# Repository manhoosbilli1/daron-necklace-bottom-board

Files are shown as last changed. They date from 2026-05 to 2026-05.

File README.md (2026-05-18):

# Daron_necklace_bottom

Bottom half of wearable LED necklace - power, haptic, USB-C charging

## At a Glance

- **Status**: Routed
- **Board size**: 20 x 20 mm
- **Layers**: 2
- **Components**: 42
- **Key ICs**:
  - U1: MCP73831-2-MC
  - U2: FH35C-11S-0.3SHW(50)_C7427016
  - U3: TPS63070RNMR
  - U7: DRV2605LDGS

## Schematic

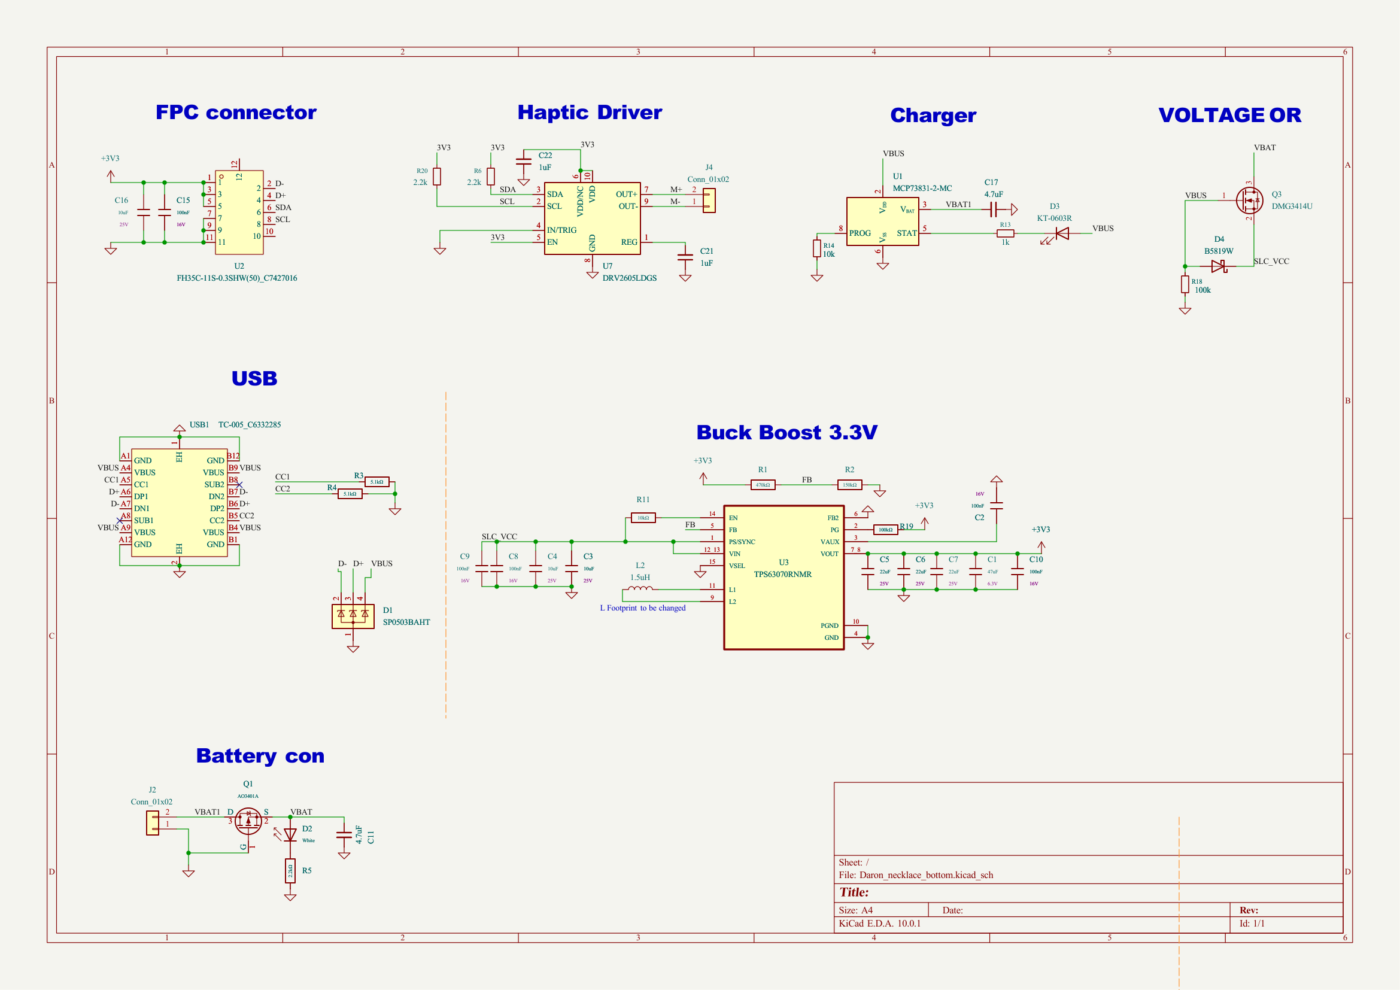
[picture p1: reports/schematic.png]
Schematic


Full PDF: [reports/schematic.pdf](reports/schematic.pdf)

## Component Roles

- **TPS63070RNMR** (U3) - buck-boost regulator (3.3 V output); handles wide LiPo voltage swing
- **DRV2605LDGS** (U7) - haptic motor driver for tactile feedback
- **MCP73831-2-MC** (U1) - single-cell LiPo charger
- **AO3401A** (Q1) - P-channel MOSFET for power switching / load enable
- **DMG3414U** (Q3) - N-channel MOSFET (companion to Q1 for full PowerPath)
- **FH35C-11S-0.3SHW** (U2) - 0.3 mm-pitch FPC connector for the top-board flex link
- **TC-005** (USB1) - micro USB-C receptacle (compact variant)
- **SP0503BAHT** (D1) - 3-line ESD protection on USB data lines
- **KT-0603R** (D3) - status LED

> Companion to the top-board (LED-driving half). The top board handles the addressable LED chain; this board handles power, charging, haptics.

## PCB

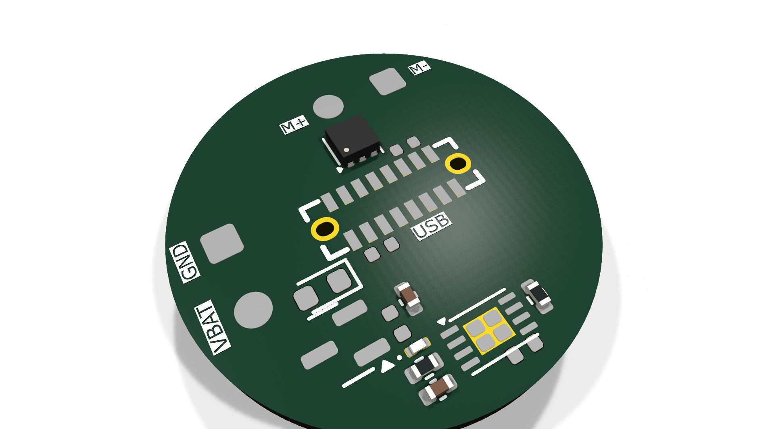
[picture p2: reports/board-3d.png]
3D top


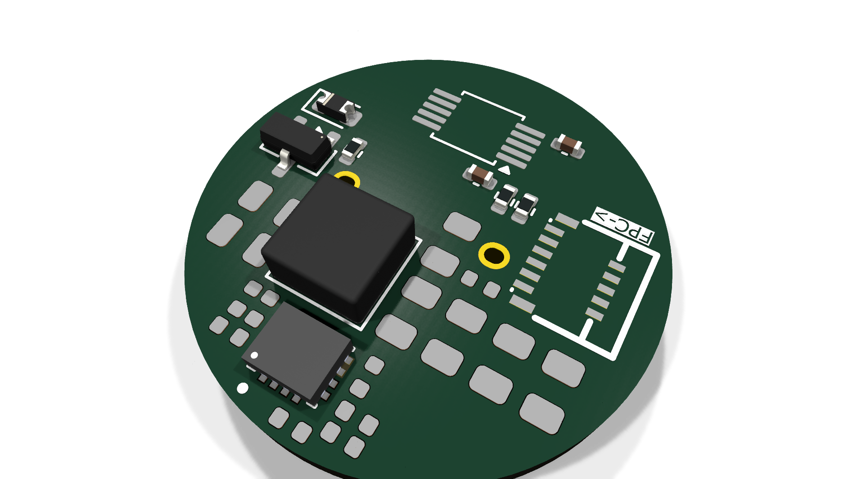
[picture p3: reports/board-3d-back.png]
3D bottom


**Top copper**

PCB top

**Bottom copper**

PCB bottom

## Bill of Materials

| Refs | Value | Footprint | Qty | MPN | LCSC |
|---|---|---|----:|-----|---|
| C1 | 47uF | PCM_JLCPCB:C_0805 | 1 |  | [C16780](https://www.lcsc.com/product-detail/_C16780.html) |
| C2,C8-C10,C15 | 100nF | PCM_JLCPCB:C_0402 | 5 |  | [C1525](https://www.lcsc.com/product-detail/_C1525.html) |
| C3,C4,C16 | 10uF | PCM_JLCPCB:C_0805 | 3 |  | [C15850](https://www.lcsc.com/product-detail/_C15850.html) |
| C5-C7 | 22uF | PCM_JLCPCB:C_0805 | 3 |  | [C45783](https://www.lcsc.com/product-detail/_C45783.html) |
| C11,C17 | 4.7uF | Capacitor_SMD:C_0402_1005Metric | 2 |  |  |
| C21,C22 | 1uF | Capacitor_SMD:C_0402_1005Metric | 2 |  |  |
| D1 | SP0503BAHT | Package_SON:WSON-6-1EP_2x2mm_P0.65mm_EP1x1.6mm | 1 |  |  |
| D2 | White | PCM_JLCPCB:D_0603 | 1 |  | [C2290](https://www.lcsc.com/product-detail/_C2290.html) |
| D3 | KT-0603R | LED_SMD:LED_0201_0603Metric | 1 |  |  |
| D4 | B5819W | Diode_SMD:D_0603_1608Metric | 1 |  |  |
| J2,J4 | Conn_01x02 | Connector_Wire:SolderWire-0.1sqmm_1x02_P3.6mm_D0.4mm_OD1mm | 2 |  |  |
| L2 | 1.5uH | Inductor_SMD:L_Coilcraft_XAL4020-XXX | 1 |  |  |
| Q1 | AO3401A | PCM_JLCPCB:Q_SOT-23 | 1 |  | [C15127](https://www.lcsc.com/product-detail/_C15127.html) |
| Q3 | DMG3414U | Package_TO_SOT_SMD:SOT-23 | 1 |  |  |
| R1 | 470kΩ | PCM_JLCPCB:R_0402 | 1 |  | [C25790](https://www.lcsc.com/product-detail/_C25790.html) |
| R2 | 150kΩ | PCM_JLCPCB:R_0402 | 1 |  | [C25755](https://www.lcsc.com/product-detail/_C25755.html) |
| R3,R4 | 5.1kΩ | PCM_JLCPCB:R_0402 | 2 |  | [C25905](https://www.lcsc.com/product-detail/_C25905.html) |
| R5 | 2.2kΩ | PCM_JLCPCB:R_0402 | 1 |  | [C25879](https://www.lcsc.com/product-detail/_C25879.html) |
| R6,R20 | 2.2k | Resistor_SMD:R_0402_1005Metric | 2 |  |  |
| R11 | 10kΩ | PCM_JLCPCB:R_0402 | 1 |  | [C25744](https://www.lcsc.com/product-detail/_C25744.html) |
| R13 | 1k | Resistor_SMD:R_0402_1005Metric | 1 |  |  |
| R14 | 10k | Resistor_SMD:R_0402_1005Metric | 1 |  |  |
| R18 | 100k | Resistor_SMD:R_0402_1005Metric | 1 |  |  |
| R19 | 100kΩ | PCM_JLCPCB:R_0402 | 1 |  | [C25741](https://www.lcsc.com/product-detail/_C25741.html) |
| U1 | MCP73831-2-MC | Package_DFN_QFN:DFN-8-1EP_3x2mm_P0.5mm_EP1.7x1.4mm | 1 |  |  |
| U2 | FH35C-11S-0.3SHW(50)_C7427016 | FH35C_11S_0_3SHW_50_:FPC-SMD_FH35C-11S-0.3SHW | 1 |  |  |
| U3 | TPS63070RNMR | TPS63070RNMR:VREG_TPS63070RNMR | 1 |  |  |
| U7 | DRV2605LDGS | Package_SO:VSSOP-10_3x3mm_P0.5mm | 1 |  |  |
| USB1 | TC-005_C6332285 | usbc:USB-C-SMD_TC-005 | 1 |  |  |

_17 of 29 line items don't have an LCSC code in the schematic - search [LCSC](https://www.lcsc.com/) or [JLC parts search](https://jlcsearch.tscircuit.com/) by MPN or footprint when sourcing._

## Files

- `Daron_necklace_bottom.kicad_pro` - KiCad project
- `Daron_necklace_bottom.kicad_sch` - schematic source
- `Daron_necklace_bottom.kicad_pcb` - PCB layout source
- `reports/schematic.pdf` - full schematic (printable)
- `reports/bom.csv` - bill of materials
- `reports/pcb-top.svg`, `reports/pcb-bottom.svg` - copper artwork
- `reports/board-stats.json` - KiCad-generated board statistics

---

_Renders and metadata auto-generated by `Backup-KiCadProject.ps1` using KiCad 10.0._

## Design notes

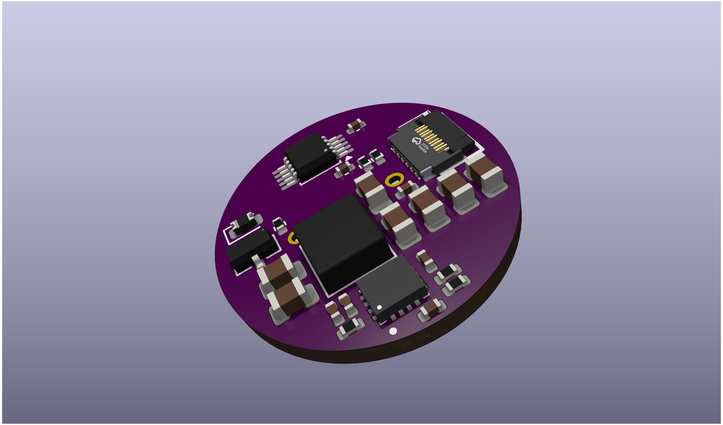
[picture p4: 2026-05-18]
pics/back_v1.png

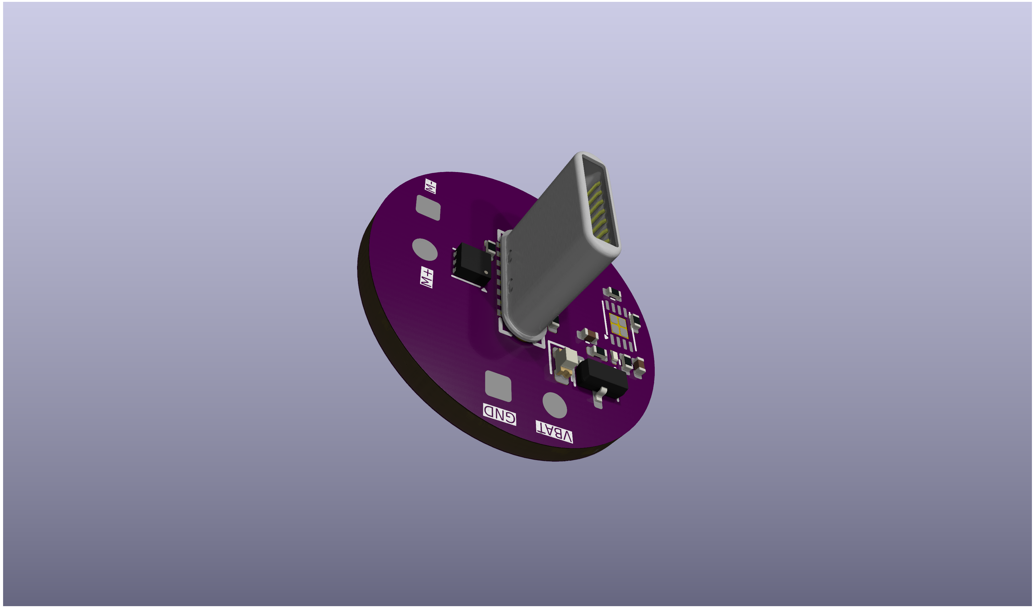
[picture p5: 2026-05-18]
pics/front_v1.png

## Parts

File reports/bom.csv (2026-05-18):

Refs | Value | Footprint | Qty | Description | Mfr | MPN | LCSC
C1 | 47uF | PCM_JLCPCB:C_0805 | 1 | 6.3V 47uF X5R ±20% 0805 Multilayer Ceramic Capacitors MLCC - SMD/SMT ROHS | Samsung Electro-Mechanics |  | C16780
C2,C8-C10,C15 | 100nF | PCM_JLCPCB:C_0402 | 5 | 16V 100nF X7R ±10% 0402 Multilayer Ceramic Capacitors MLCC - SMD/SMT ROHS | Samsung Electro-Mechanics |  | C1525
C3,C4,C16 | 10uF | PCM_JLCPCB:C_0805 | 3 | 25V 10uF X5R ±10% 0805 Multilayer Ceramic Capacitors MLCC - SMD/SMT ROHS | Samsung Electro-Mechanics |  | C15850
C5-C7 | 22uF | PCM_JLCPCB:C_0805 | 3 | 25V 22uF X5R ±20% 0805 Multilayer Ceramic Capacitors MLCC - SMD/SMT ROHS | Samsung Electro-Mechanics |  | C45783
C11,C17 | 4.7uF | Capacitor_SMD:C_0402_1005Metric | 2 | Unpolarized capacitor, small symbol
C21,C22 | 1uF | Capacitor_SMD:C_0402_1005Metric | 2 | Unpolarized capacitor, small symbol
D1 | SP0503BAHT | Package_SON:WSON-6-1EP_2x2mm_P0.65mm_EP1x1.6mm | 1 | TVS Diode Array, 5.5V Standoff, 3 Channels, SOT-143 package
D2 | White | PCM_JLCPCB:D_0603 | 1 | White 0603 LED Indication - Discrete ROHS | Hubei KENTO Elec |  | C2290
D3 | KT-0603R | LED_SMD:LED_0201_0603Metric | 1 | Light emitting diode
D4 | B5819W | Diode_SMD:D_0603_1608Metric | 1 | Schottky diode
J2,J4 | Conn_01x02 | Connector_Wire:SolderWire-0.1sqmm_1x02_P3.6mm_D0.4mm_OD1mm | 2 | Generic connector, single row, 01x02, script generated (kicad-library-utils/schlib/autogen/connector/)
L2 | 1.5uH | Inductor_SMD:L_Coilcraft_XAL4020-XXX | 1 | Inductor
Q1 | AO3401A | PCM_JLCPCB:Q_SOT-23 | 1 | 30V 4A 44mΩ@10V,4.3A 1.4W 1.3V@250uA 1 Piece P-Channel SOT-23 MOSFETs ROHS | Alpha & Omega Semicon |  | C15127
Q3 | DMG3414U | Package_TO_SOT_SMD:SOT-23 | 1 | 4.2A Id, 20V Vds, N-Channel MOSFET, SOT-23
R1 | 470kΩ | PCM_JLCPCB:R_0402 | 1 | 62.5mW Thick Film Resistors 50V ±100ppm/°C ±1% 470kΩ 0402 Chip Resistor - Surface Mount ROHS | UNI-ROYAL(Uniroyal Elec) |  | C25790
R2 | 150kΩ | PCM_JLCPCB:R_0402 | 1 | 62.5mW Thick Film Resistors 50V ±100ppm/°C ±1% 150kΩ 0402 Chip Resistor - Surface Mount ROHS | UNI-ROYAL(Uniroyal Elec) |  | C25755
R3,R4 | 5.1kΩ | PCM_JLCPCB:R_0402 | 2 | 62.5mW Thick Film Resistors 50V ±100ppm/°C ±1% 5.1kΩ 0402 Chip Resistor - Surface Mount ROHS | UNI-ROYAL(Uniroyal Elec) |  | C25905
R5 | 2.2kΩ | PCM_JLCPCB:R_0402 | 1 | 62.5mW Thick Film Resistors 50V ±100ppm/°C ±1% 2.2kΩ 0402 Chip Resistor - Surface Mount ROHS | UNI-ROYAL(Uniroyal Elec) |  | C25879
R6,R20 | 2.2k | Resistor_SMD:R_0402_1005Metric | 2 | Resistor, small symbol
R11 | 10kΩ | PCM_JLCPCB:R_0402 | 1 | 62.5mW Thick Film Resistors 50V ±100ppm/°C ±1% 10kΩ 0402 Chip Resistor - Surface Mount ROHS | UNI-ROYAL(Uniroyal Elec) |  | C25744
R13 | 1k | Resistor_SMD:R_0402_1005Metric | 1 | Resistor, small symbol
R14 | 10k | Resistor_SMD:R_0402_1005Metric | 1 | Resistor, small symbol
R18 | 100k | Resistor_SMD:R_0402_1005Metric | 1 | Resistor, small symbol
R19 | 100kΩ | PCM_JLCPCB:R_0402 | 1 | 62.5mW Thick Film Resistors 50V ±100ppm/°C ±1% 100kΩ 0402 Chip Resistor - Surface Mount ROHS | UNI-ROYAL(Uniroyal Elec) |  | C25741
U1 | MCP73831-2-MC | Package_DFN_QFN:DFN-8-1EP_3x2mm_P0.5mm_EP1.7x1.4mm | 1 | Single cell, Li-Ion/Li-Po charge management controller, 4.20V, Tri-State Status Output, in DFN-8 package
U2 | FH35C-11S-0.3SHW(50)_C7427016 | FH35C_11S_0_3SHW_50_:FPC-SMD_FH35C-11S-0.3SHW | 1
U3 | TPS63070RNMR | TPS63070RNMR:VREG_TPS63070RNMR | 1
U7 | DRV2605LDGS | Package_SO:VSSOP-10_3x3mm_P0.5mm | 1 | Haptic driver for LRAs and ERMs with effect library, 2-5.2V, VSSOP-10
USB1 | TC-005_C6332285 | usbc:USB-C-SMD_TC-005 | 1

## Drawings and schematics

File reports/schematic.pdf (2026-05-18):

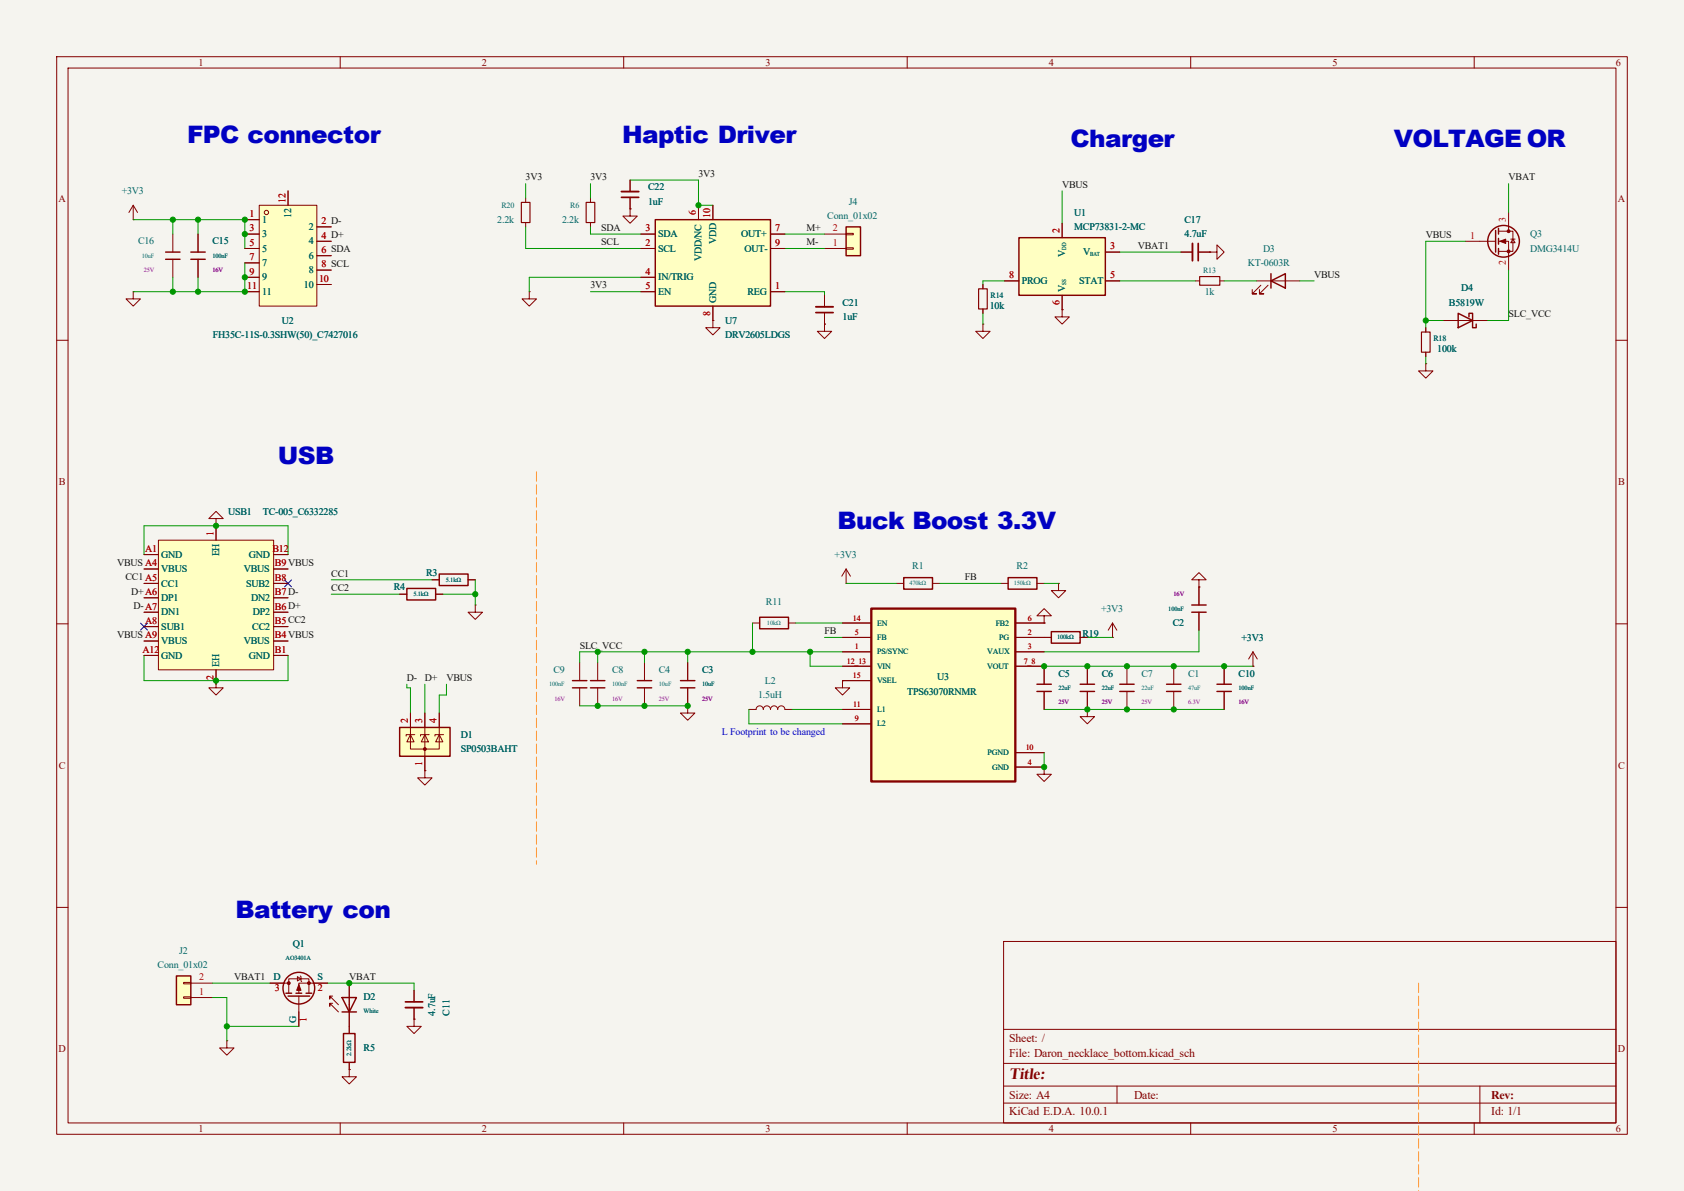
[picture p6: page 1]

2 GND A1 VBUS A4 CC1 A5 DP1 A6 DN1 A7 SUB1 A8 VBUS A9 GND A12 GND B1 VBUS B4 CC2 B5 DP2 B6 DN2 B7 SUB2 B8 VBUS B9 GND B12 USB1 TC-005_C6332285 R3

2 GND A1 VBUS A4 CC1 A5 DP1 A6 DN1 A7 SUB1 A8 VBUS A9 GND A12 GND B1 VBUS B4 CC2 B5 DP2 B6 DN2 B7 SUB2 B8 VBUS B9 GND B12 R3

L Footprint to be changed

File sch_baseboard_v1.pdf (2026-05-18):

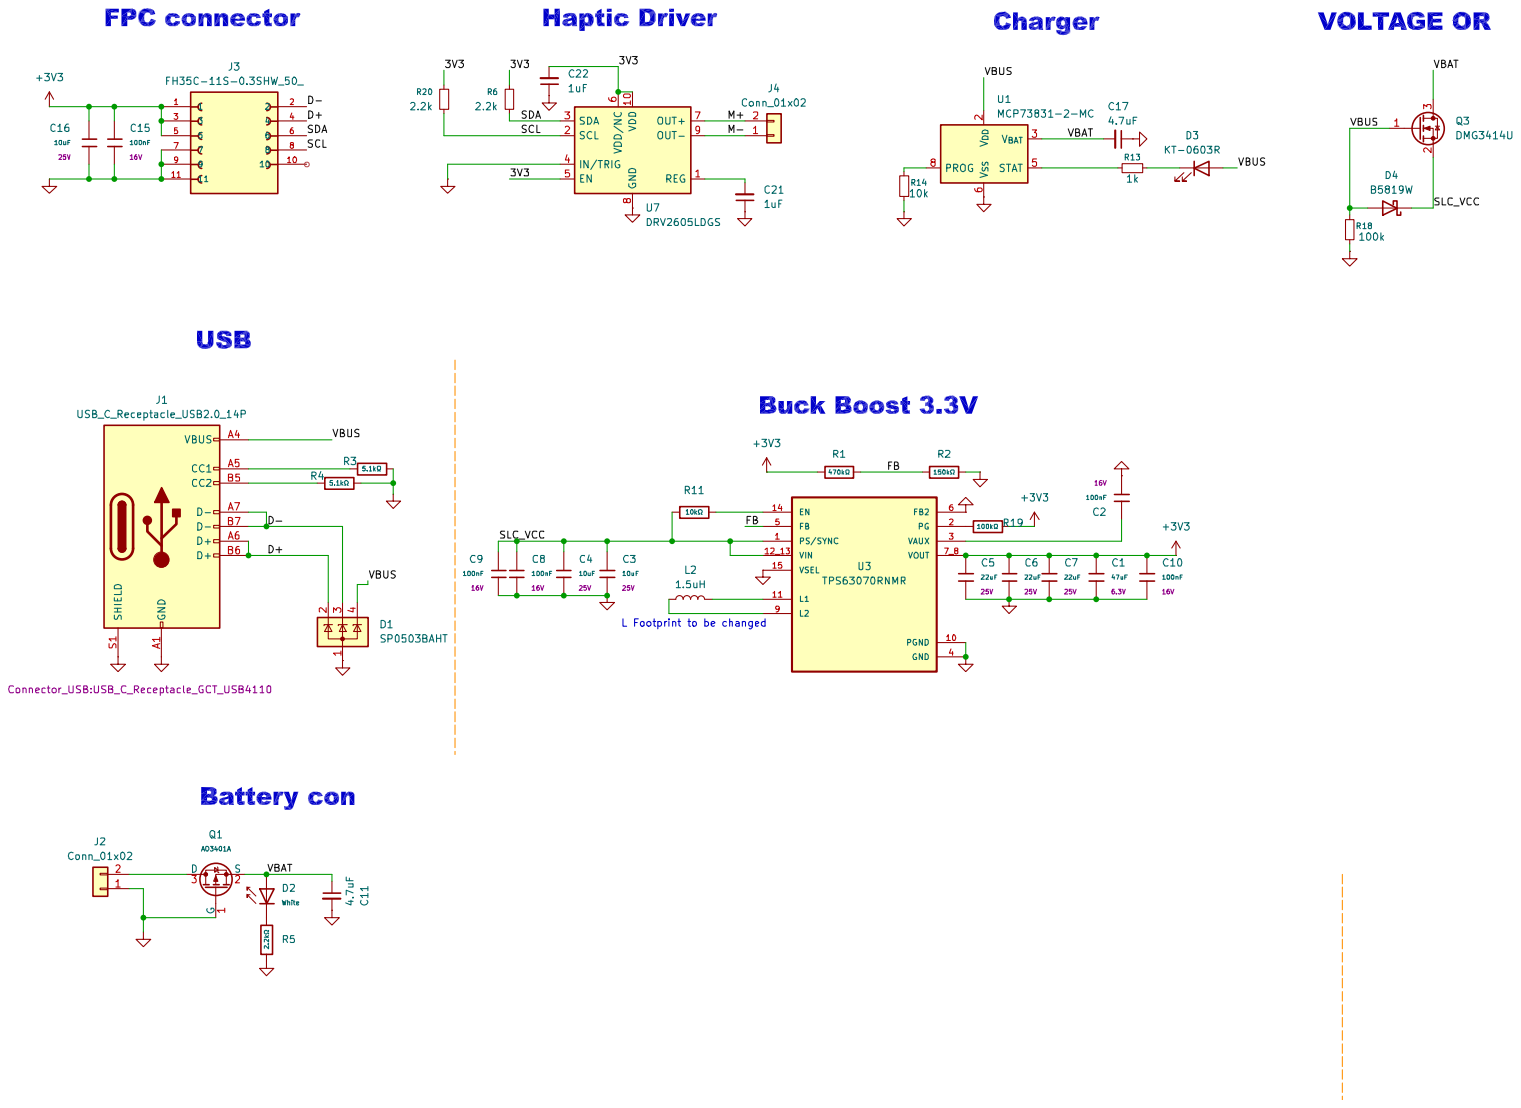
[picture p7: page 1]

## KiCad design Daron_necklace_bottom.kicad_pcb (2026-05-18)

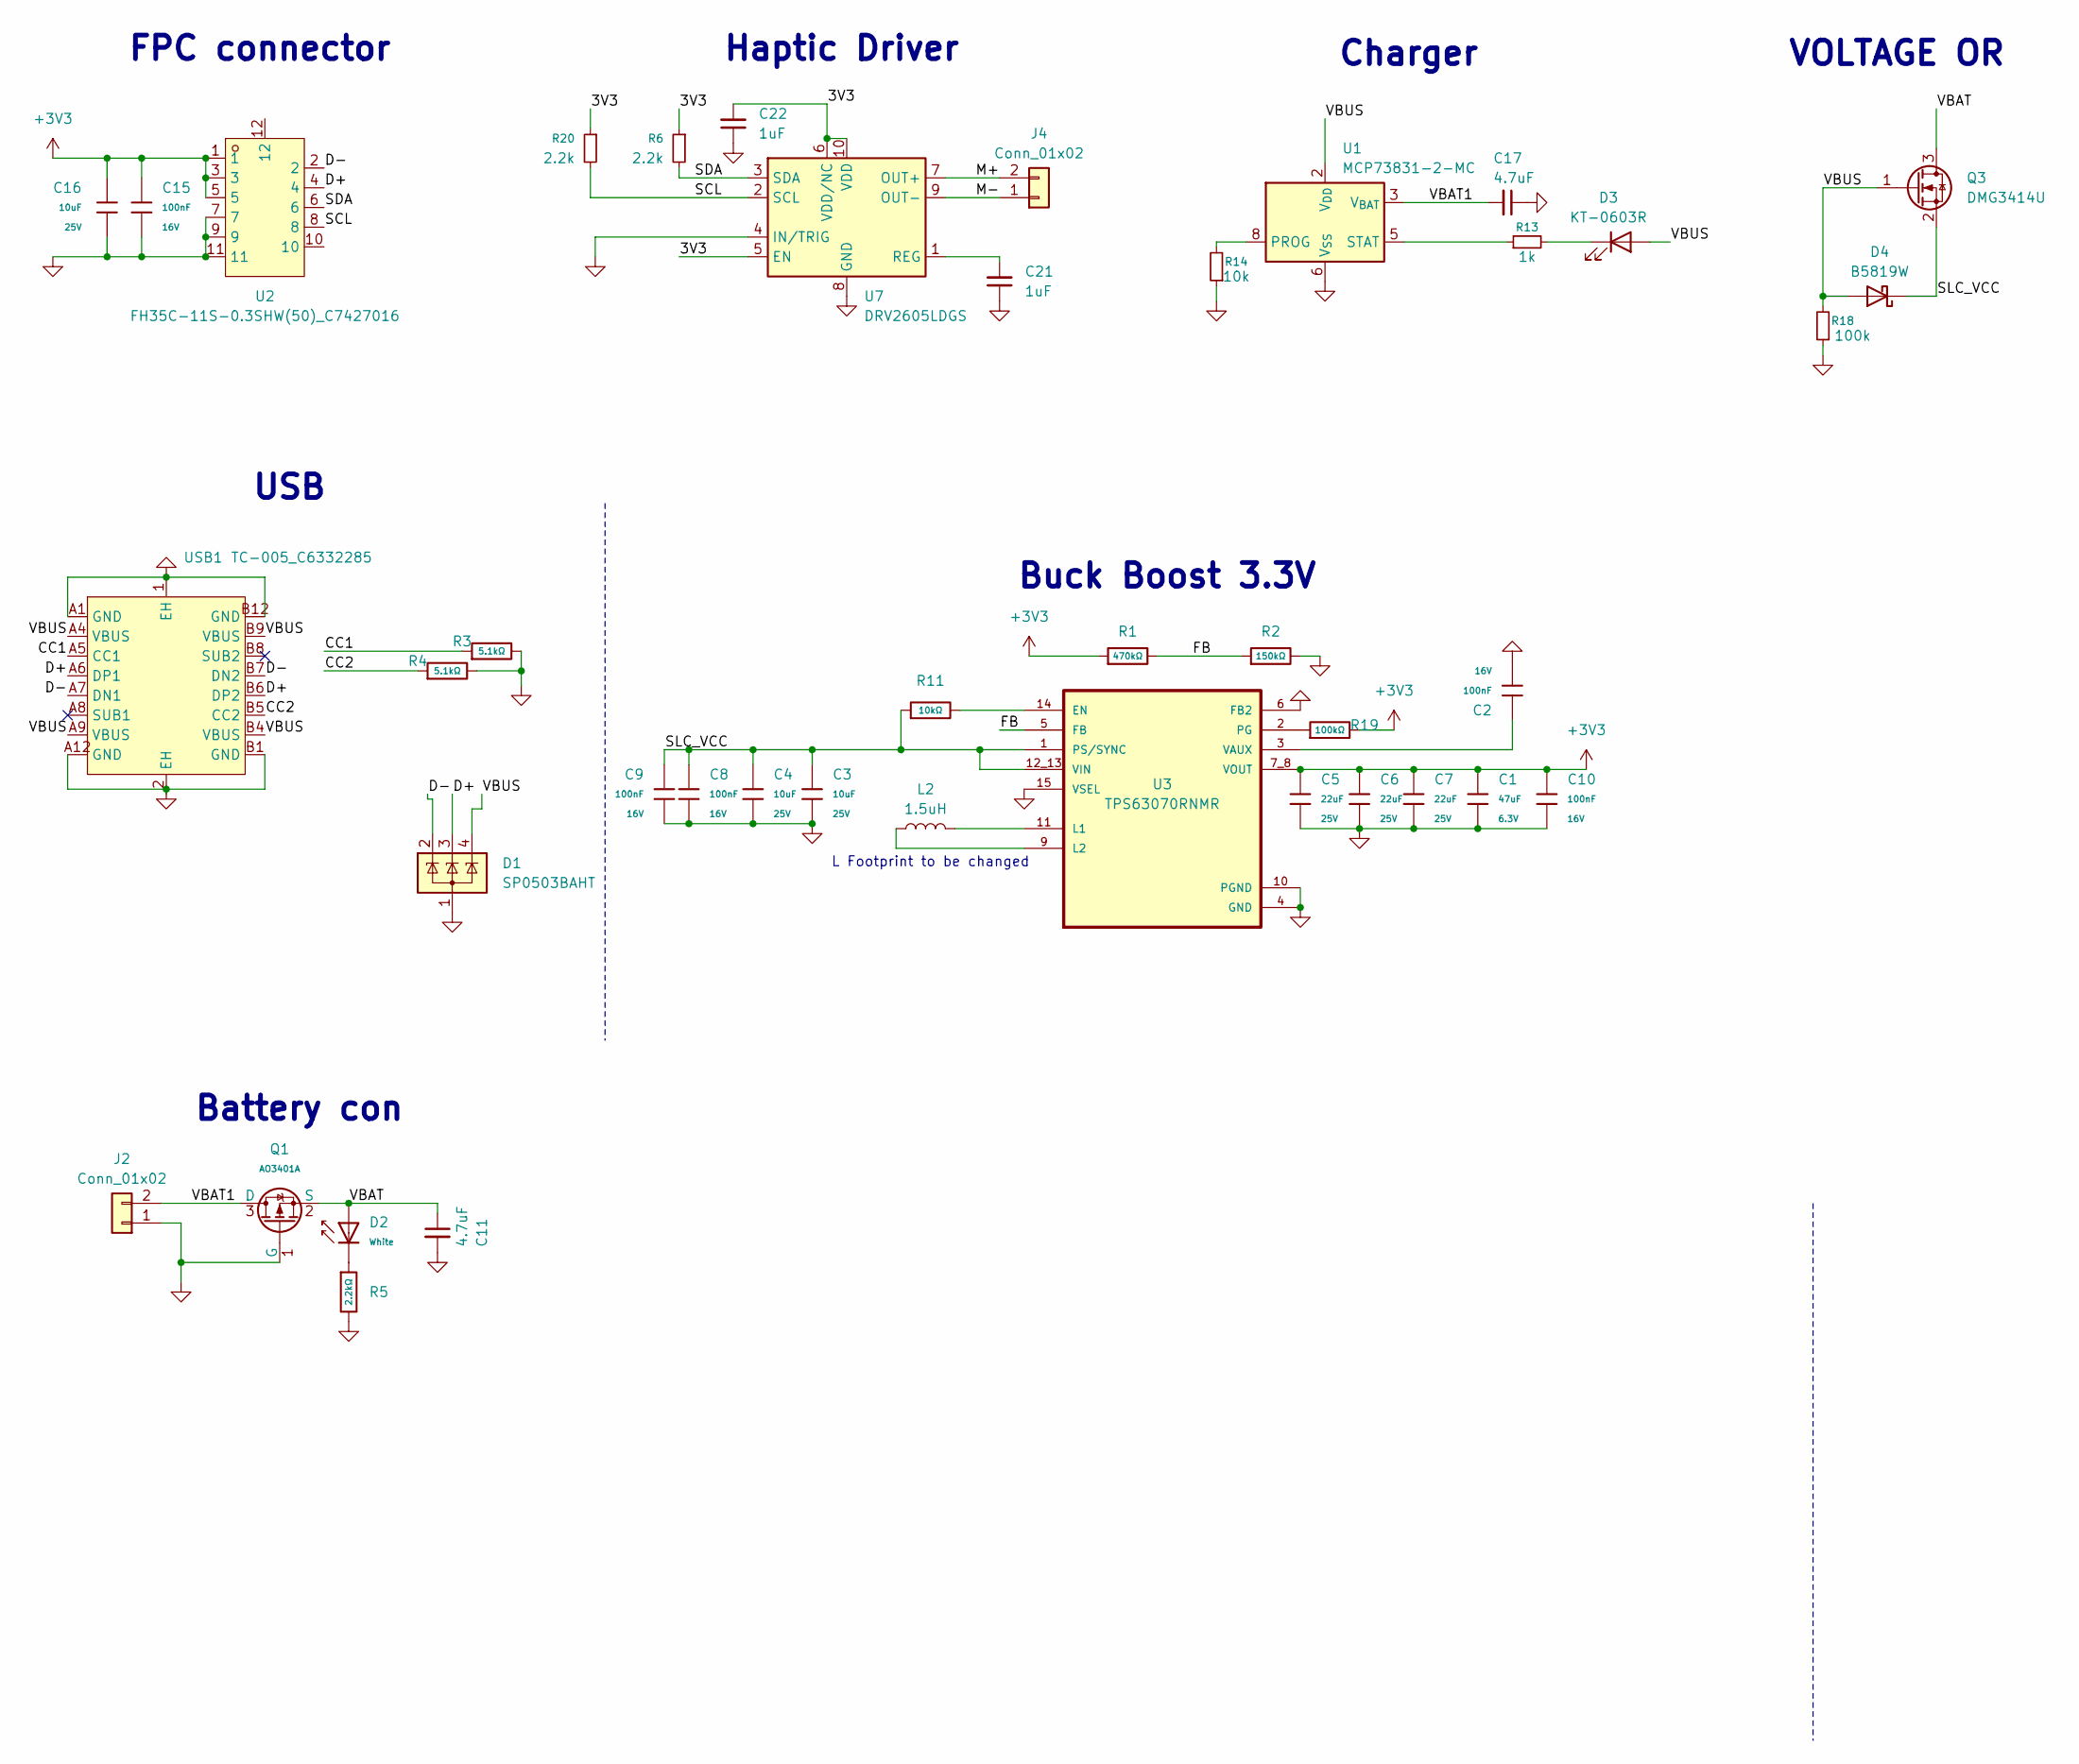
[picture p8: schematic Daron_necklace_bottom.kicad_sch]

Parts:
C1: 47uF; C_0805; Voltage Rated 6.3V; Tolerance ±20%; Part CL21A476MQYNNNE; LCSC C16780
C2, C8, C9, C10, C15: 100nF; C_0402; Voltage Rated 16V; Tolerance ±10%; Part CL05B104KO5NNNC; LCSC C1525
C3, C4, C16: 10uF; C_0805; Voltage Rated 25V; Tolerance ±10%; Part CL21A106KAYNNNE; LCSC C15850
C5, C6, C7: 22uF; C_0805; Voltage Rated 25V; Tolerance ±20%; Part CL21A226MAQNNNE; LCSC C45783
C11, C17: 4.7uF; C_0402_1005Metric
C21, C22: 1uF; C_0402_1005Metric
D1: SP0503BAHT; WSON-6-1EP_2x2mm_P0.65mm_EP1x1.6mm
D2: White; D_0603; Part KT-0603W; LCSC C2290
D3: KT-0603R; LED_0201_0603Metric
D4: B5819W; D_0603_1608Metric
J2, J4: Conn_01x02; SolderWire-0.1sqmm_1x02_P3.6mm_D0.4mm_OD1mm
L2: 1.5uH; L_Coilcraft_XAL4020-XXX
Q1: AO3401A; Q_SOT-23; Part AO3401A; LCSC C15127
Q3: DMG3414U; SOT-23
R1: 470kΩ; R_0402; Overload Voltage (Max) 50V; Tolerance ±1%; Part 0402WGF4703TCE; LCSC C25790
R2: 150kΩ; R_0402; Overload Voltage (Max) 50V; Tolerance ±1%; Part 0402WGF1503TCE; LCSC C25755
R3, R4: 5.1kΩ; R_0402; Overload Voltage (Max) 50V; Tolerance ±1%; Part 0402WGF5101TCE; LCSC C25905
R5: 2.2kΩ; R_0402; Overload Voltage (Max) 50V; Tolerance ±1%; Part 0402WGF2201TCE; LCSC C25879
R6, R20: 2.2k; R_0402_1005Metric
R11: 10kΩ; R_0402; Overload Voltage (Max) 50V; Tolerance ±1%; Part 0402WGF1002TCE; LCSC C25744
R13: 1k; R_0402_1005Metric
R14: 10k; R_0402_1005Metric
R18: 100k; R_0402_1005Metric
R19: 100kΩ; R_0402; Overload Voltage (Max) 50V; Tolerance ±1%; Part 0402WGF1003TCE; LCSC C25741
U1: MCP73831-2-MC; DFN-8-1EP_3x2mm_P0.5mm_EP1.7x1.4mm
U2: FH35C-11S-0.3SHW(50)_C7427016; FPC-SMD_FH35C-11S-0.3SHW; LCSC Part C7427016
U3: TPS63070RNMR; VREG_TPS63070RNMR
U7: DRV2605LDGS; VSSOP-10_3x3mm_P0.5mm
USB1: TC-005_C6332285; USB-C-SMD_TC-005; LCSC Part C6332285

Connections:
+3V3: C1.1, C5.1, C6.1, C7.1, C10.1, C15.1, C16.1, R1.1, R19.2, U2.1, U2.3, U2.5, U3.7_8 (VOUT)
/3V3: C22.2, R6.1, R20.1, U7.5 (EN), U7.6 (VDD/NC), U7.10 (VDD)
/CC1: R3.1, USB1.A5 (CC1)
/CC2: R4.1, USB1.B5 (CC2)
/D+: D1.3 (K), U2.4, USB1.A6 (DP1), USB1.B6 (DP2)
/D-: D1.2 (K), U2.2, USB1.A7 (DN1), USB1.B7 (DN2)
/FB: R1.2, R2.1, U3.5 (FB)
/M+: J4.2, U7.7 (OUT+)
/M-: J4.1, U7.9 (OUT-)
/SCL: R20.2, U2.8, U7.2 (SCL)
/SDA: R6.2, U2.6, U7.3 (SDA)
/SLC_VCC: C3.1, C4.1, C8.1, C9.1, D4.1 (K), Q3.2 (S), R11.1, U3.1 (PS/SYNC), U3.12_13 (VIN)
/VBAT: C11.1, D2.2, Q1.2 (S), Q3.3 (D)
/VBAT1: C17.2, J2.2, Q1.3 (D), U1.3 (V_{BAT}), U1.4 (V_{BAT})
/VBUS: D1.4 (K), D3.2 (A), D4.2 (A), Q3.1 (G), R18.2, U1.1 (V_{DD}), U1.2 (V_{DD}), USB1.A4 (VBUS), USB1.A9 (VBUS), USB1.B4 (VBUS), USB1.B9 (VBUS)
GND: C1.2, C2.2, C3.2, C4.2, C5.2, C6.2, C7.2, C8.2, C9.2, C10.2, C11.2, C15.2, C16.2, C17.1, C21.1, C22.1, D1.1 (A), J2.1, Q1.1 (G), R2.2, R3.2, R4.2, R5.2, R14.1, R18.1, U1.6 (V_{SS}), U2.7, U2.9, U2.11, U3.4 (GND), U3.6 (FB2), U3.10 (PGND), U3.15 (VSEL), U7.4 (IN/TRIG), U7.8 (GND), USB1.1 (EH), USB1.2 (EH), USB1.A1 (GND), USB1.A12 (GND), USB1.B1 (GND), USB1.B12 (GND)
unnamed: D2.1, R5.1
unnamed: D3.1 (K), R13.2
unnamed: R14.2, U1.8 (PROG)
unnamed: R13.1, U1.5 (STAT)
unnamed: R11.2, U3.14 (EN)
unnamed: L2.2, U3.11 (L1)
unnamed: L2.1, U3.9 (L2)
unnamed: R19.1, U3.2 (PG)
unnamed: C2.1, U3.3 (VAUX)
unnamed: C21.2, U7.1 (REG)

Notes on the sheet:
Battery con
Charger
VOLTAGE OR
Buck Boost 3.3V
USB
L Footprint to be changed
FPC connector
Haptic Driver

Board: 2 copper layers, 42 parts (26 on the bottom side), 26 nets, no tracks yet.

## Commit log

2026-05-18 Update backup artifacts
    [Daron_necklace_bottom.kicad_pcb, Daron_necklace_bottom.kicad_sch, bom.csv]
2026-05-18 Enrich README: schematic PNG, component roles, BOM table
